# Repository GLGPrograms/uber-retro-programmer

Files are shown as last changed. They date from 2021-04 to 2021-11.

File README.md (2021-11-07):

# ÜRP - Über Retro Programmer

An EEPROM programmer for retro playing.
- Can dump most parallel (EE)PROM memories, like 27xxx and 28xxx.
- Supports RW operations of most 28Cxxx EEPROM.
- Suppport may be extended to flash memories up to 1MiB.

## What's inside

This repository is organized as follows
```
ÜRP
 |__ hw          --> KiCAD schematics
 |   |__ gerbers  -> fabrication files (gerbers)
 |   |__ urp.pdf  -> PDF schematic
 |   |__ urp.pro  -> KiCAD project
 |__ fw          --> source code for atmega 328
 |__ sw          --> source code for PC Command Line Interface
 |__ docs        --> files related to documentation
```

After clone, init submodules:
```
git submodule update
````

## PCB Assembly

|Designator | Description | Notes |
|---|---|---|
|C1-C5 | capacitor ceramic 100n P5.08 | |
|C6-C7 | capacitor ceramic 22p P2.54  | |
|R1 | resistor 10k | |
|R2-R4 | resistor 330 | |
|Y1 | crystal 16M | |
|SW1 | Tactile switch | |
|D1-D3 | LED 5mm | e.g. green, yellow, red |
|U1 | microcontroller ATMega 328 | |
|U2 U3 | shift register 74HC595 | |
|JP1-JP5 | 3-pin header 2.54 | EEPROM size selection |
|J1 | 6-pin header 2.54 | |
|J2 | ZIF socket 32 pin wide | |
|J3 | 2-pin header 2.54 | optional |
|R5 | resistor 10k | optional |
|R6 | resistor 3k3 | optional |
|Q1 | PMOS (2N7002) | optional |

**Warning:** When Q1 is not mounted, JP7 must be shorted.

## How to compile and load firmware

1. Mount atmega328 on an Arduino UNO board or equivalent. If is a fresh chip, you must load an Arduino compatible bootloader (e.g. optiboot).

1. Compile firmware in `fw` folder using the makefile. Change `/dev/ttyXYZ123` with the correct serial port (e.g. /dev/ttyUSB0);

```
cd fw
make
make program AVRDUDEPORT=/dev/ttyXYZ123
```

1. Move the atmega328 on the ÜRP.

### How to use EEPROM size selection pins

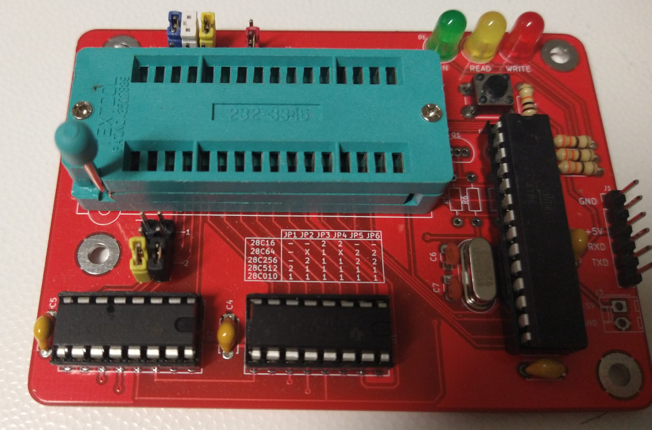
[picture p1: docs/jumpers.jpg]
Jumpers


Jumpers JP1-JP6 must be placed according to memory size and technology.
Each jumper has three positions, 1 (green), 2 (red) or unmounted (gray).
Please refer to the following tables for correct placement.

#### EEPROM pinout

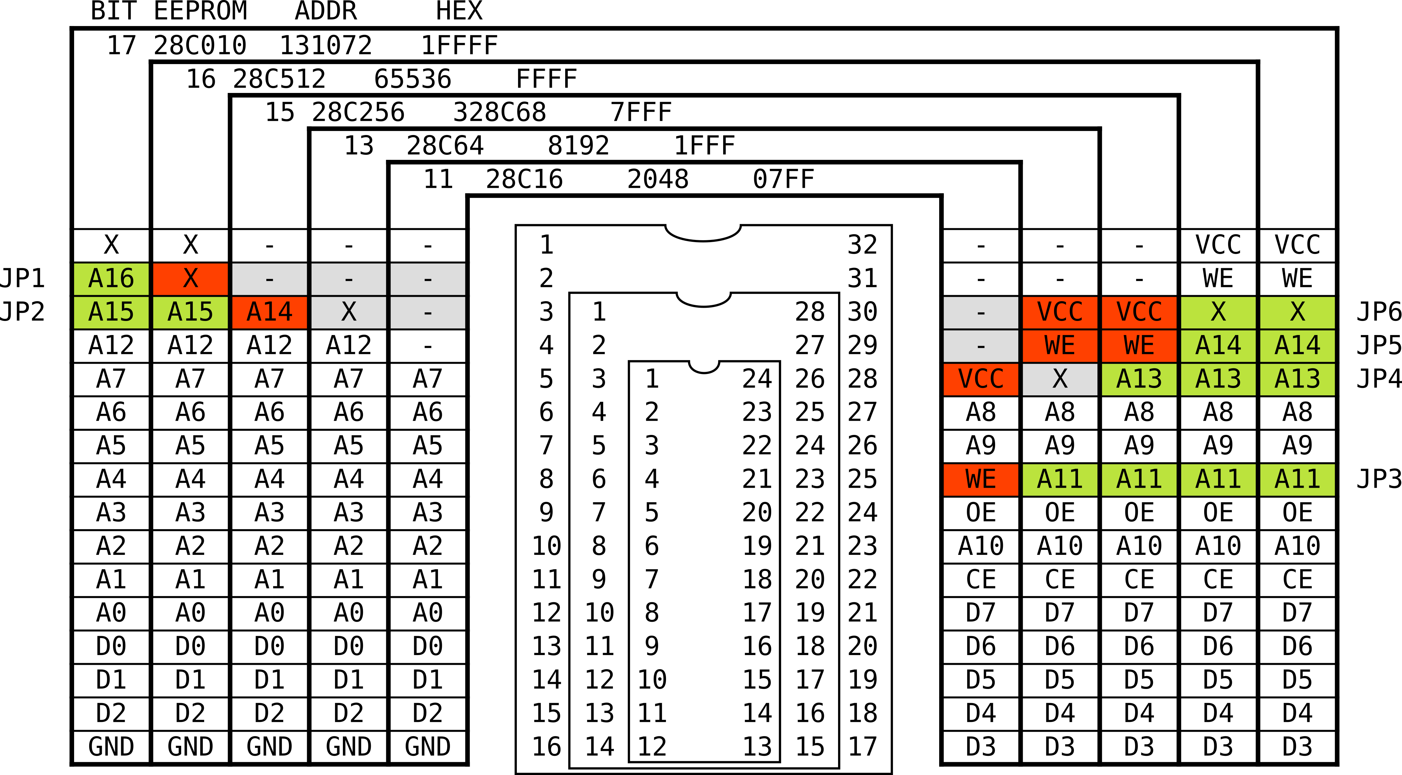
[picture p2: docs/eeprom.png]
eeprom pinout


#### EPROM pinout

**Notes:**
- EPROM support is read only;
- Most EPROM have VPP on JP2. Datasheet recommends to put VPP=VCC during reading operations. I often keep JP2 in position (1) and make read operations starting from 32768 (A15=VCC).

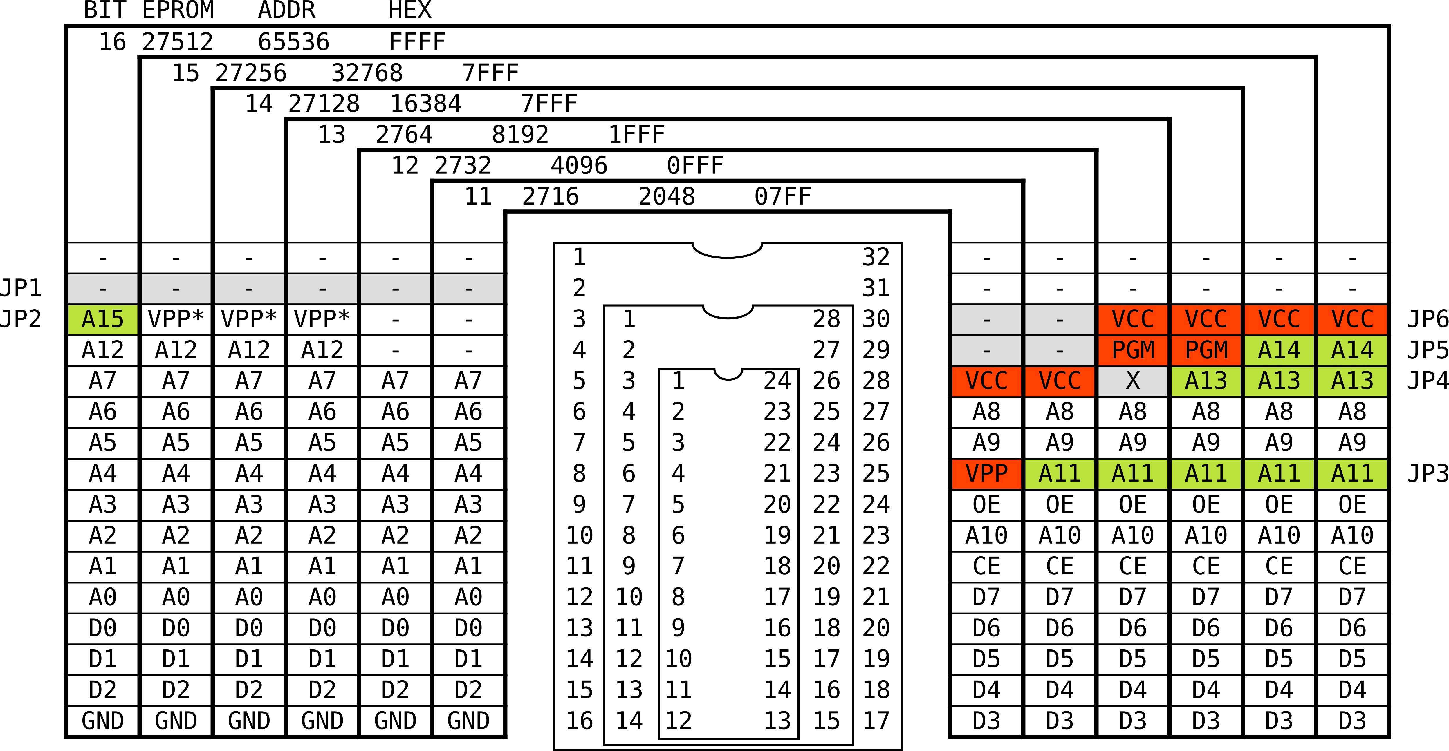
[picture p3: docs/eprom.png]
eprom pinout


## How to compile CLI

    cd sw
    make

### CLI options

    Usage: ./serprog options

    -r --read arg                read the content of eeprom in file. Must specify size and addr
    -w --write arg               write the content of file in eeprom, then verify. Must specify addr
    -v --verify arg              verify the content of the file with the eeprom. Must specify addr
    -n --noverify                skip verification after write
    -e --erase                   erase the eeprom (by software, i.e. write FF)
    -V --verbose [arg]           set verbosity level to arg (0 low, 7 high)
    -s --size arg                set reading size
    -a --addr arg                set starting address (default 0)
    -d --device arg              set serial device (default /dev/ttyUSB0)
    -U --unlock                  unlock before
    -P --lock                    lock after
    -h --help                    print this help

#### Read a 28C256 EEPROM (8KiB)

    ./serprog --device /dev/ttyACMx --read dump.bin -s 8192

#### Write a binary image

    ./serprog --device /dev/ttyACMx --write dump.bin

If the EEPROM fails verify, SDP (Software Data Protection) may be on.
Try disabling.

    ./serprog --device /dev/ttyACMx -U --write dump.bin

In both cases, size is deducted from the binary image.

#### Manually verify against a binary image

    ./serprog --device /dev/ttyACMx --verify dump.bin

Size is deducted from the binary image.

#### Protect EEPROM with SDP

    ./serprog --device /dev/ttyACMx -P

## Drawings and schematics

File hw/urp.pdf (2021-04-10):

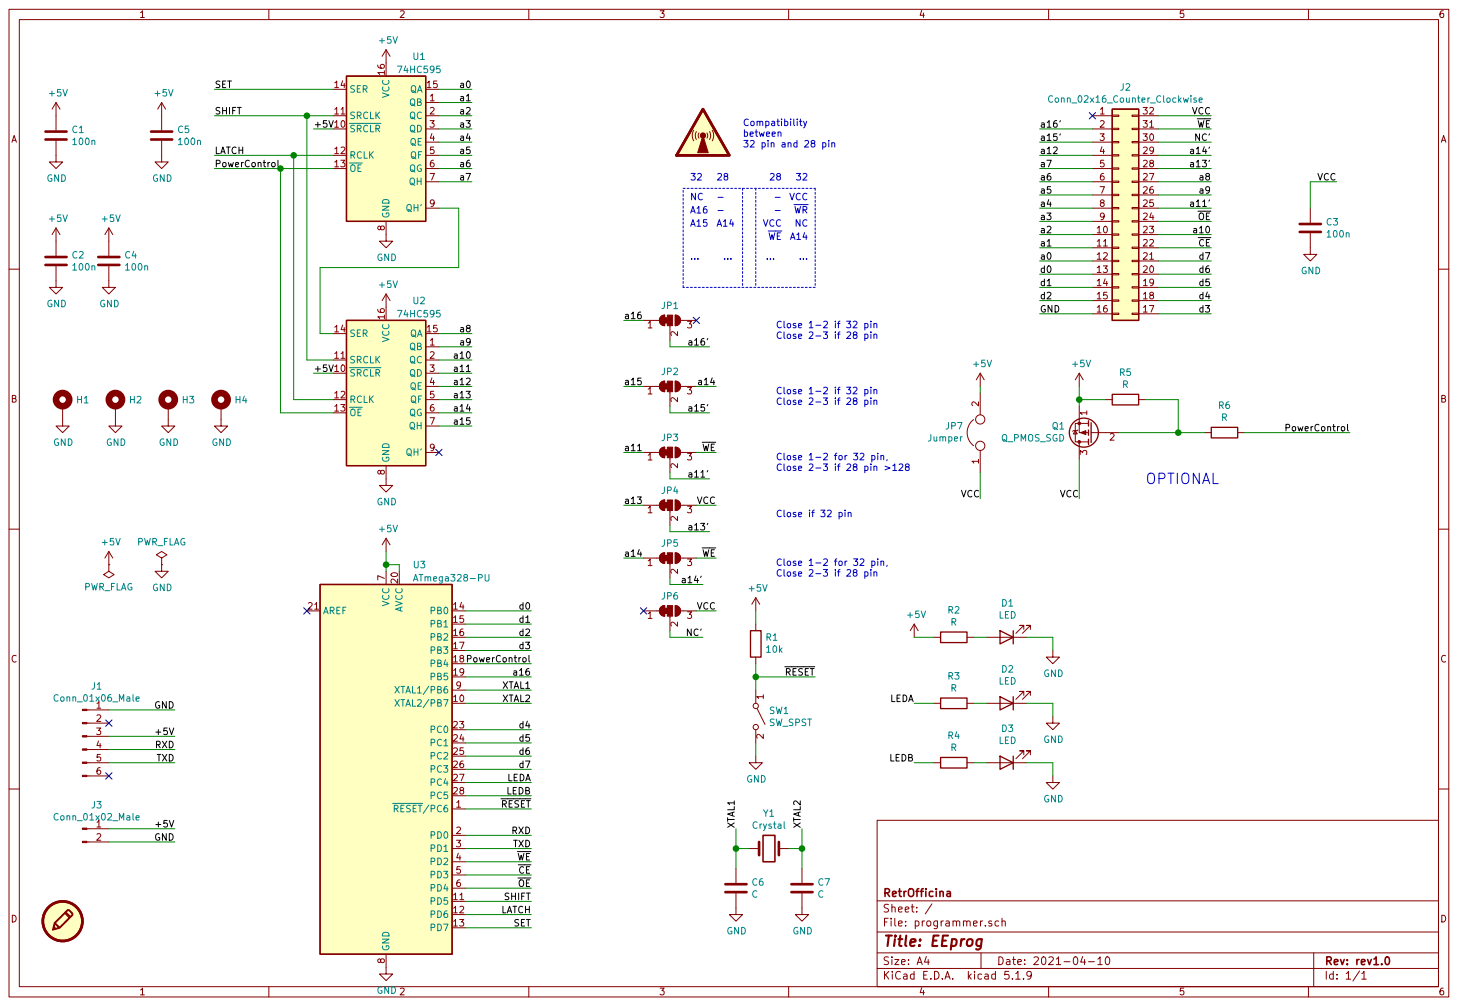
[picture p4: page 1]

Close 2-3 if 28 pin NC

File: programmer.sch Sheet: / RetrOfficina

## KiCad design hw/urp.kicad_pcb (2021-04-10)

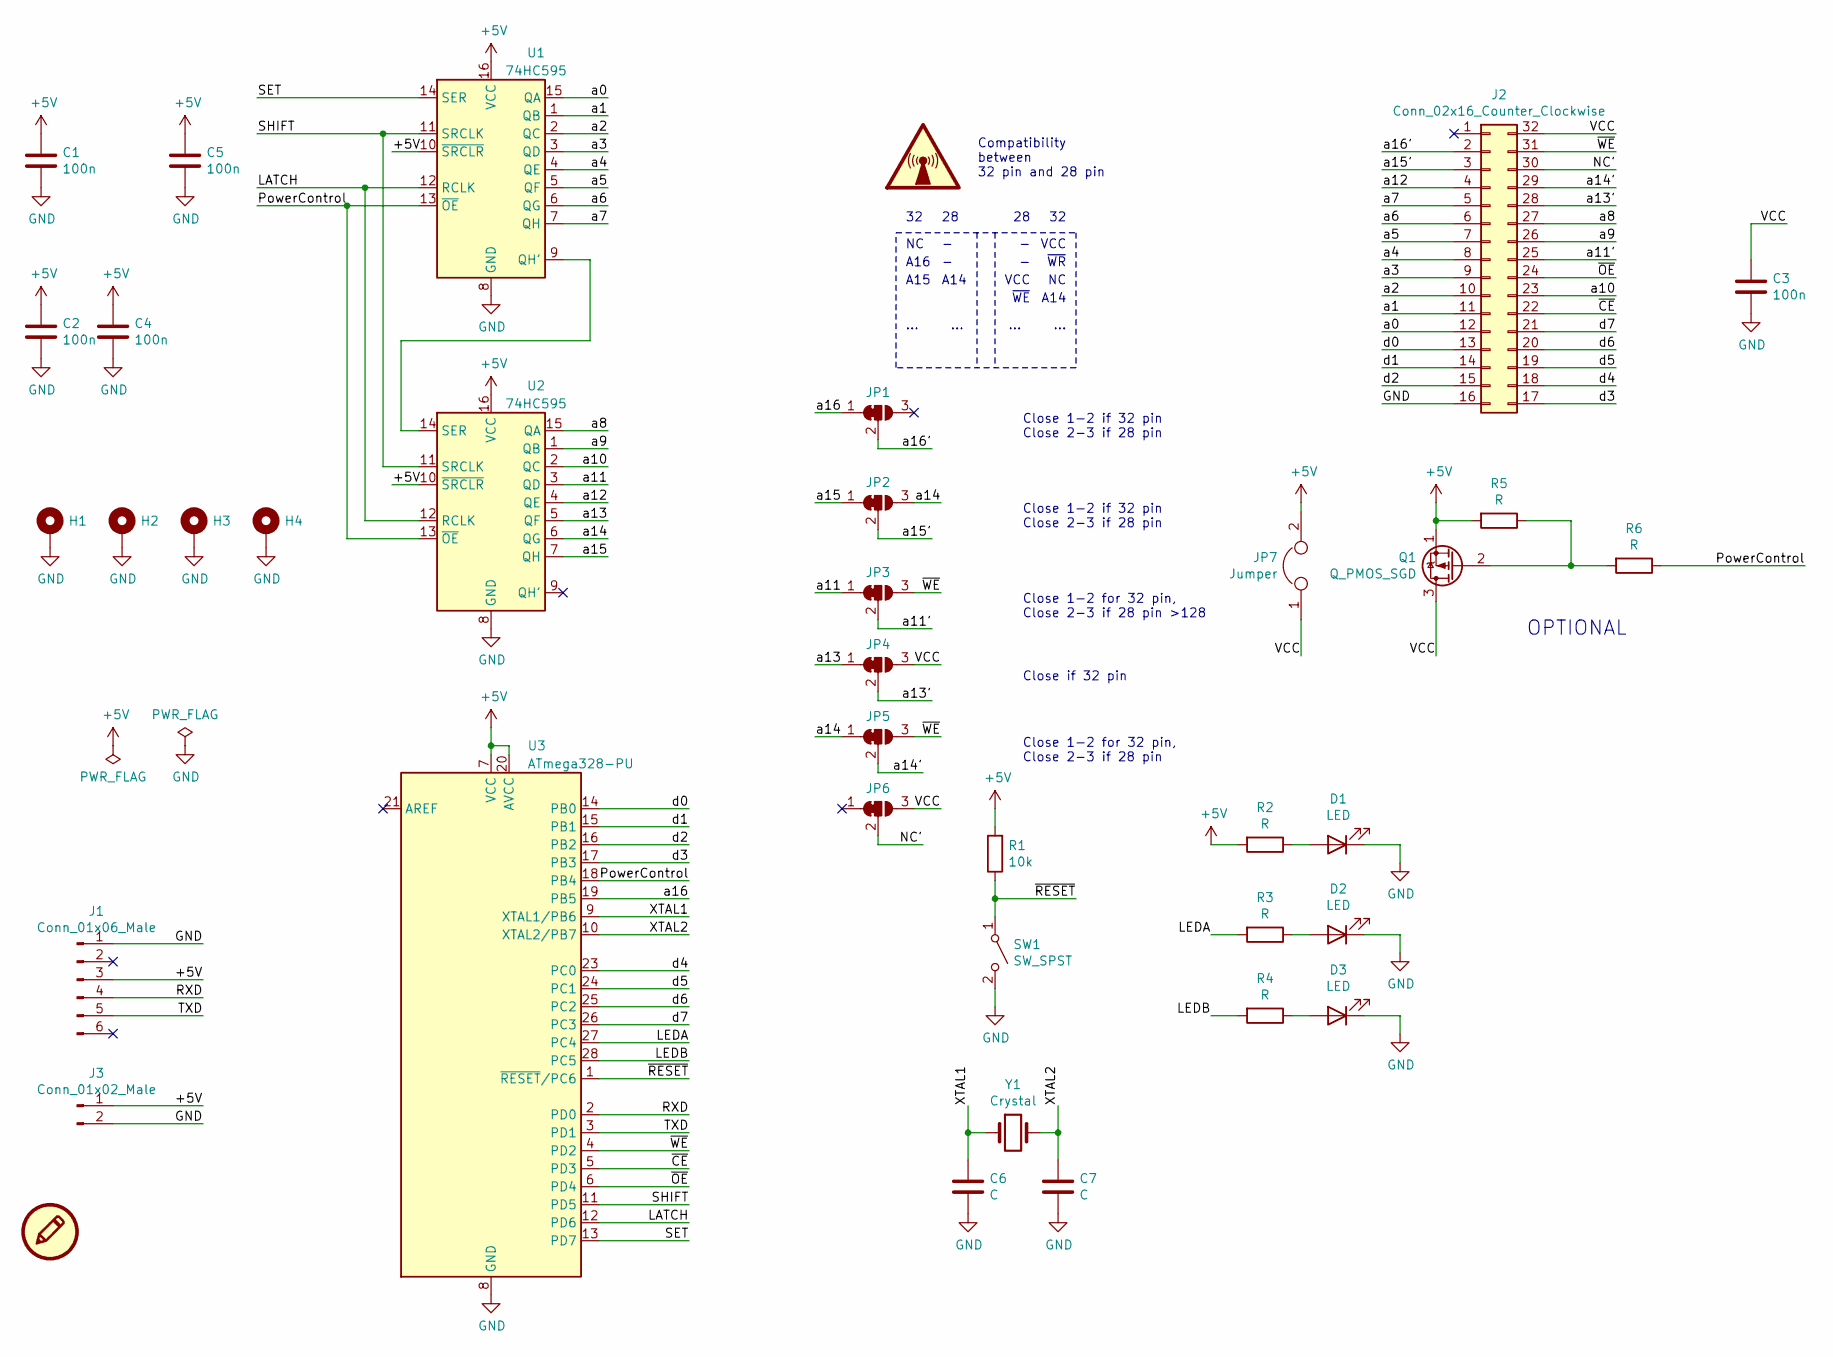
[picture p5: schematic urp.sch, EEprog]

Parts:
C1, C2, C3, C4, C5: 100n; C_Disc_D4.7mm_W2.5mm_P5.00mm
C6, C7: C; C_Disc_D3.0mm_W1.6mm_P2.50mm
D1, D2, D3: LED; LED_D5.0mm
H1, H2, H3, H4: MountingHole_Pad; MountingHole_3.2mm_M3_Pad
J1: Conn_01x06_Male; PinHeader_1x06_P2.54mm_Vertical
J2: Conn_02x16_Counter_Clockwise; DIP_Socket-32_W11.9_W12.7_W15.24_W17.78_W18.5_3M_232-1285-0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
J3: Conn_01x02_Male; Molex_KK-254_AE-6410-02A_1x02_P2.54mm_Vertical
JP1, JP2, JP3, JP4, JP5, JP6: SolderJumper_3_Bridged12; PinHeader_1x03_P2.54mm_Vertical
JP7: Jumper; SolderJumper-2_P1.3mm_Open_TrianglePad1.0x1.5mm
Q1: Q_PMOS_SGD; TO-92_Inline
R1: 10k; R_Axial_DIN0204_L3.6mm_D1.6mm_P7.62mm_Horizontal
R2, R3, R4, R5, R6: R; R_Axial_DIN0204_L3.6mm_D1.6mm_P7.62mm_Horizontal
SW1: SW_SPST; SW_PUSH_6mm_H4.3mm
SYM1: GraphicSymbol
U1, U2: 74HC595; DIP-16_W7.62mm_Socket_LongPads
U3: ATmega328-PU; DIP-28_W7.62mm
Y1: Crystal; Crystal_HC49-4H_Vertical

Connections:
+5V: C1.1, C2.1, C4.1, C5.1, J1.3, J3.1, JP7.2, Q1.1 (S), R1.2, R2.2, R5.2, U1.10 (~SRCLR), U1.16 (VCC), U2.10 (~SRCLR), U2.16 (VCC), U3.7 (VCC), U3.20 (AVCC)
/LATCH: U1.12 (RCLK), U2.12 (RCLK), U3.12 (PD6)
/LEDA: R3.2, U3.27 (PC4)
/LEDB: R4.2, U3.28 (PC5)
/NC': J2.30, JP6.2 (C)
/PowerControl: R6.1, U1.13 (~OE), U2.13 (~OE), U3.18 (PB4)
/RXD: J1.4, U3.2 (PD0)
/SET: U1.14 (SER), U3.13 (PD7)
/SHIFT: U1.11 (SRCLK), U2.11 (SRCLK), U3.11 (PD5)
/TXD: J1.5, U3.3 (PD1)
/VCC: C3.1, J2.32, JP4.3 (B), JP6.3 (B), JP7.1, Q1.3 (D)
/XTAL1: C6.1, U3.9 (XTAL1/PB6), Y1.1
/XTAL2: C7.1, U3.10 (XTAL2/PB7), Y1.2
/a0: J2.12, U1.15 (QA)
/a1: J2.11, U1.1 (QB)
/a2: J2.10, U1.2 (QC)
/a3: J2.9, U1.3 (QD)
/a4: J2.8, U1.4 (QE)
/a5: J2.7, U1.5 (QF)
/a6: J2.6, U1.6 (QG)
/a7: J2.5, U1.7 (QH)
/a8: J2.27, U2.15 (QA)
/a9: J2.26, U2.1 (QB)
/a10: J2.23, U2.2 (QC)
/a11: JP3.1 (A), U2.3 (QD)
/a11': J2.25, JP3.2 (C)
/a12: J2.4, U2.4 (QE)
/a13: JP4.1 (A), U2.5 (QF)
/a13': J2.28, JP4.2 (C)
/a14: JP2.3 (B), JP5.1 (A), U2.6 (QG)
/a14': J2.29, JP5.2 (C)
/a15: JP2.1 (A), U2.7 (QH)
/a15': J2.3, JP2.2 (C)
/a16: JP1.1 (A), U3.19 (PB5)
/a16': J2.2, JP1.2 (C)
/d0: J2.13, U3.14 (PB0)
/d1: J2.14, U3.15 (PB1)
/d2: J2.15, U3.16 (PB2)
/d3: J2.17, U3.17 (PB3)
/d4: J2.18, U3.23 (PC0)
/d5: J2.19, U3.24 (PC1)
/d6: J2.20, U3.25 (PC2)
/d7: J2.21, U3.26 (PC3)
/~CE: J2.22, U3.5 (PD3)
/~OE: J2.24, U3.6 (PD4)
/~RESET: R1.1, SW1.1 (A), U3.1 (~RESET~/PC6)
/~WE: J2.31, JP3.3 (B), JP5.3 (B), U3.4 (PD2)
GND: C1.2, C2.2, C3.2, C4.2, C5.2, C6.2, C7.2, D1.1 (K), D2.1 (K), D3.1 (K), H1.1, H2.1, H3.1, H4.1, J1.1, J2.16, J3.2, SW1.2 (B), U1.8 (GND), U2.8 (GND), U3.8 (GND), U3.22 (GND)
unnamed: D1.2 (A), R2.1
unnamed: D2.2 (A), R3.1
unnamed: D3.2 (A), R4.1
unnamed: Q1.2 (G), R5.1, R6.2
unnamed: U1.9 (QH'), U2.14 (SER)

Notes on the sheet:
Compatibility between 32 pin and 28 pin
A16
A15
A14
...
VCC
~WR
~WE
Close 1-2 if 32 pin Close 2-3 if 28 pin
Close 1-2 for 32 pin, Close 2-3 if 28 pin >128
Close if 32 pin
Close 1-2 for 32 pin, Close 2-3 if 28 pin
OPTIONAL

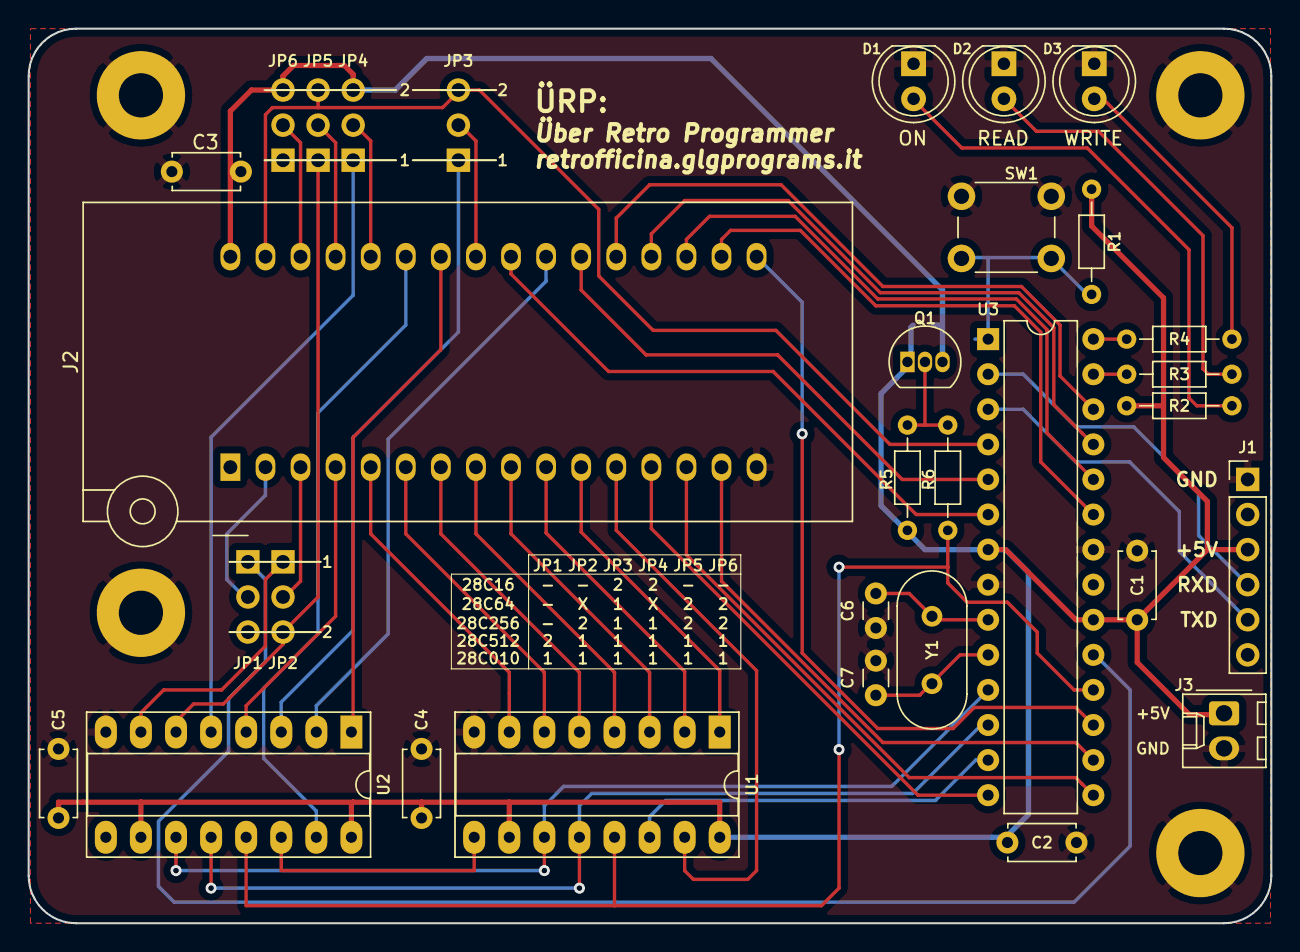
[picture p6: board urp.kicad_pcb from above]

Board: 2 copper layers, 90.0 x 64.8 mm, 36 parts (1 on the bottom side), 53 nets.

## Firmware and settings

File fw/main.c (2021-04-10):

/*
 * This file is part of the frser-avr project.
 *
 * Copyright (C) 2009 Urja Rannikko <urjaman@gmail.com>
 *
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
 * You should have received a copy of the GNU General Public License
 * along with this program; if not, write to the Free Software
 * Foundation, Inc., 51 Franklin St, Fifth Floor, Boston, MA  02110-1301 USA
 */

#include "main.h"
#include "flash.h"
#include "frser.h"
#include "uart.h"

void reader(void);

/*
 * This file is part of the frser-avr project.
 *
 * Copyright (C) 2009 Urja Rannikko <urjaman@gmail.com>
 *
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
 * You should have received a copy of the GNU General Public License
 * along with this program; if not, write to the Free Software
 * Foundation, Inc., 51 Franklin St, Fifth Floor, Boston, MA  02110-1301 USA
 */

#include "main.h"
#include "uart.h"
#include "flash.h"
#include "frser.h"


int main(void) {
	cli();
	uart_init();
	flash_init();
	frser_main();
}

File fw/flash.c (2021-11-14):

/*
 * This file is part of the frser-avr project.
 *
 * Copyright (C) 2009,2015 Urja Rannikko <urjaman@gmail.com>
 *
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
 * You should have received a copy of the GNU General Public License
 * along with this program; if not, write to the Free Software
 * Foundation, Inc., 51 Franklin St, Fifth Floor, Boston, MA  02110-1301 USA
 */

#include "main.h"
#include "flash.h"
#include "uart.h"

static uint32_t errors_cnt = 0;

static uint8_t flash_databus_read(void) {
	uint8_t rv;
	rv = (PINB & 0x0F);
	rv |= ((PINC & 0x0F) << 4);
	return rv;
}

static void flash_databus_tristate(void) {
	// Lower nibble of databus - as input
	DDRB &= ~(0x0F);
	// Higher nibble of databus - as input
	DDRC &= ~(0x0F);

	// Lower nibble of databus - no pullup
	PORTB &= ~(0x0F);
	// Higher nibble of databus - no pullup
	PORTC &= ~(0x0F);
}

static void flash_databus_output(unsigned char data) {
	// Lower nibble of databus
	PORTB = ((PORTB & 0xF0) | (data & 0x0F));
	// Higher nibble of databus
	PORTC = ((PORTC & 0xF0) | ((data >> 4) & 0x0F));
	// Lower nibble of databus
	DDRB |= (0x0F);
	// Higher nibble of databus
	DDRC |= (0x0F);
}

static void flash_chip_enable(void) {
	PORTD &= ~_BV(3);
}

static void flash_chip_disable(void) {
	PORTD |= _BV(3);
}

void flash_init(void) {
	// Init info leds
	DDRC |= _BV(4) | _BV(5);

	// Shift, latch and set
	PORTD &= ~ (_BV(5) | _BV(6) | _BV(7));
	DDRD |= _BV(5) | _BV(6) | _BV(7);
	// a16 is out of shift registers
	PORTB &= ~_BV(5);
	DDRB |= _BV(5);
	// ADDR unit init done
	
	// Powercontrol
	PORTB |= _BV(4);
	DDRB |= _BV(4);
	
	// ~WE, ~CE, ~OE
	PORTD |= (_BV(2) | _BV(3) | _BV(4));
	DDRD |= (_BV(2) | _BV(3) | _BV(4));
	// control bus init done
	
	// hmm, i should probably tristate the data bus by default...
	flash_databus_tristate();
	// CE control is not absolutely necessary...
	flash_chip_enable();
	
	// _delay_ms(100);
	
	// flash_disable_protection();
	
	// _delay_ms(100);
	

}

void flash_error_cnt_reset(void) {
	errors_cnt = 0;
}

uint32_t flash_error_cnt() {
	return errors_cnt;
}

static void flash_output_enable(void) {
	PORTD &= ~_BV(4);
}

static void flash_output_disable(void) {
	PORTD |= _BV(4);
}

static void flash_setaddr(uint32_t addr) {
	uint8_t a16 = (addr >> 16) & 1;
	
	uint8_t part = addr >> 8;
	for (uint8_t i = 8; i > 0; i--) {
		uint8_t bit = part & 0x80;
		if (bit)
			PORTD |= _BV(7);
		else
			PORTD &= ~_BV(7);
		
		// Shift pulse
		// _delay_us(1);
		asm("nop\n\rnop");
		PORTD |= _BV(5);
		asm("nop\n\rnop");
		// _delay_us(1);
		PORTD &= ~_BV(5);
		
		part <<= 1;
	}
	
	part = addr;
	for (int i = 8; i > 0; i--) {
		uint8_t bit = part & 0x80;
		if (bit)
			PORTD |= _BV(7);
		else
			PORTD &= ~_BV(7);
		
		// Shift pulse
		// _delay_us(1);
		asm("nop\n\rnop");
		PORTD |= _BV(5);
		asm("nop\n\rnop");
		// _delay_us(1);
		PORTD &= ~_BV(5);
		
		part <<= 1;
	}
	
	if (a16)
		PORTB |= _BV(5);
	else
		PORTB &= ~_BV(5);
	
	// Pulse latch
	// _delay_us(1);
	asm("nop\n\rnop");
	PORTD |= _BV(6);
	asm("nop\n\rnop");
	// _delay_us(1);
	PORTD &= ~_BV(6);
}

static void flash_pulse_we(void) {
	_delay_us(1);
	PORTD &= ~(_BV(2));
	_delay_us(1);
	PORTD |= _BV(2);
}

static void flash_read_init(void) {
	flash_databus_tristate();
	flash_output_enable();
}

// assume chip enabled & output enabled & databus tristate
static uint8_t flash_readcycle(uint32_t addr) {
	_delay_us(1);
	flash_setaddr(addr);
	_delay_us(1);
	return flash_databus_read();
}

// assume only CE, and perform single cycle
uint8_t flash_read(uint32_t addr) {
	// turn on read led
	PORTC |= _BV(4);

	uint8_t data;
	flash_read_init();
	flash_setaddr(addr);
	data = flash_databus_read();
	flash_output_disable();

	// turn off read led
	PORTC &= ~_BV(4);
	
	return data;
}

uint8_t data_polling(const uint8_t val) {
	uint8_t ret = 1;
	_delay_us(1);
	flash_databus_tristate();
	for (uint16_t i = 0; i < 0xFFFF && ret != 0; i++) {
		flash_output_enable();
		_delay_us(1);
		if (val == flash_databus_read())
			ret = 0;
		flash_output_disable();
		_delay_us(1);
	}
	return ret;
}

// assume only CE, perform single cycle
void flash_write(uint32_t addr, uint8_t data) {
	// turn on write led
	PORTC |= _BV(5);

	flash_output_disable();
	flash_databus_output(data);
	flash_setaddr(addr);
	flash_pulse_we();
	errors_cnt += data_polling(data);

	// turn off write led
	PORTC &= ~_BV(5);
}

// assume only CE, perform single cycle
void flash_write_fast(uint32_t addr, uint8_t data) {
	// turn on write led
	PORTC |= _BV(5);

	flash_output_disable();
	flash_databus_output(data);
	flash_setaddr(addr);
	flash_pulse_we();

	// turn off write led
	PORTC &= ~_BV(5);
}

// assume only CE, perform whole cycle
void flash_writen(uint32_t addr, uint8_t* data, uint32_t len) {
	// turn on write led
	PORTC |= _BV(5);

	flash_output_disable();

	do {
		flash_setaddr(addr++);
		flash_databus_output(*(data));
		flash_pulse_we();
		errors_cnt += data_polling(*data);
		data++;
	} while(--len);

	// turn off write led
	PORTC &= ~_BV(5);
}

void flash_readn(uint32_t addr, uint32_t len) {
	// turn on read led
	PORTC |= _BV(4);

	flash_read_init();
	do {
		SEND(flash_readcycle(addr++));
	} while(--len);
	// safety features
	flash_output_disable();

	// turn off read led
	PORTC &= ~_BV(4);
}

void flash_select_protocol(uint8_t allowed_protocols) {
	(void)allowed_protocols;
	flash_init();

	// Turn on power supply
	PORTB &= ~_BV(4);
}

void flash_set_safe(void) {
	// Turn off power supply
	// PORTB |= _BV(4);
}

static void flash_pulse_we_short(void) {
  PORTD &= ~(_BV(2));
  PORTD |= _BV(2);
}

static void flash_write_sync(const uint16_t addr, const uint8_t data) {
  flash_databus_output(data);
  flash_setaddr(addr);
  flash_pulse_we();
}

void flash_reset_sdp(void) {
  flash_output_disable();

  flash_write_fast(0x5555, 0xaa);
  flash_write_fast(0x2aaa, 0x55);
  flash_write_fast(0x5555, 0x80);
  flash_write_fast(0x5555, 0xaa);
  flash_write_fast(0x2aaa, 0x55);
  flash_write_fast(0x5555, 0x20);

	// turn on leds in sequence
	PORTC |= _BV(5);
	PORTC |= _BV(4);
	_delay_ms(500);
	PORTC &= ~_BV(4);
	PORTC &= ~_BV(5);
}

void flash_set_sdp(void) {
  flash_output_disable();
	
	flash_write_fast(0x5555, 0xaa);
  flash_write_fast(0x2aaa, 0x55);
  flash_write_fast(0x5555, 0xa0);

		// turn on leds in sequence
	PORTC |= _BV(5);
	PORTC |= _BV(4);
	_delay_ms(500);
	PORTC &= ~_BV(4);
	_delay_ms(500);
	PORTC &= ~_BV(5);
}

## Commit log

2021-04-10 Fist commit
    [urp-B_Cu.gbl, urp-B_Mask.gbs, urp-B_SilkS.gbo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]
2021-04-11 [FW] Custom libfrser (+flash_writen method); Support for RW leds
2021-04-11 [SW] Print read hexdump only if verbose
2021-08-20 Pezze per far funzionare sia l'SDP che la scrittura.
    - FIXME: L'sdp funziona per miracolo in ambo i versi facendo una doppia scrittura nell'opbuf.
    - FIXME: La scrittura funziona bene a blocchi (ma quasi sicuramente anche
    sparsa) a patto che si committi l'opbuf ad ogni operazione.
    - La dimensione dell'opbuf è stata portata manualmente a 1024.
    Vale la pena implementare la lettura dello stack per trimmare questo valore.
    [flash.c]
2021-10-24 Bugfix in flash write check.
    Now the flash write check is more readable. And maybe really works as
    inteded.
    [flash.c]
2021-11-14 [fw] fixed writing for slower roms
    - Longer data polling timeout
    - Plus, fixed typo in data polling value
    [flash.c]

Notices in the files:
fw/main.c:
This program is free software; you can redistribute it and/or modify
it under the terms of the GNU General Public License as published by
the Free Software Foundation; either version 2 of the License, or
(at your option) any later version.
